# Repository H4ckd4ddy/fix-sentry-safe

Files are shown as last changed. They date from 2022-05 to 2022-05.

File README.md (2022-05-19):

# How to fix a safe

A vulnerability allow to open electronic safes from Sentry Safe and Master Lock without any pin code.

This repository contain alternative PCB and firmware to patch this issue.

For more detail about the vulnerability, [check this repo](https://github.com/H4ckd4ddy/bypass-sentry-safe)

### PCB

| Version | Design | Description |
| :-----: | :---: | :--- |
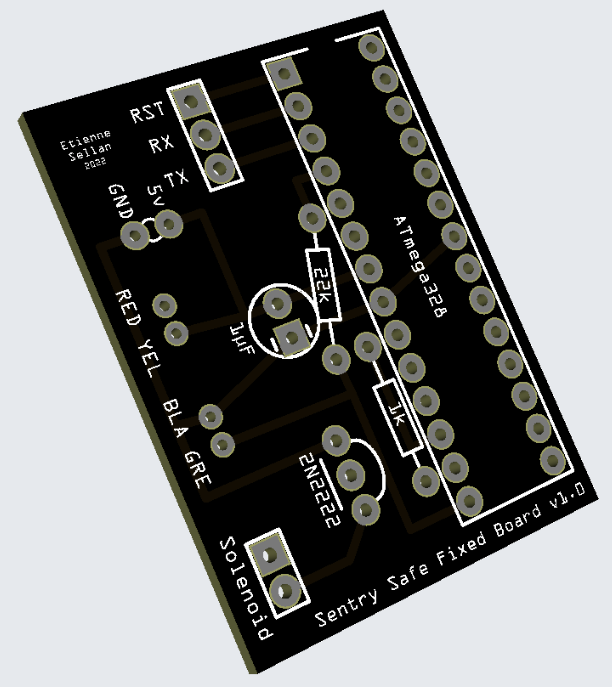
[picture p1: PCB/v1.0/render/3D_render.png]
| v1.0 |  | Only ATmega328, basic offline features |
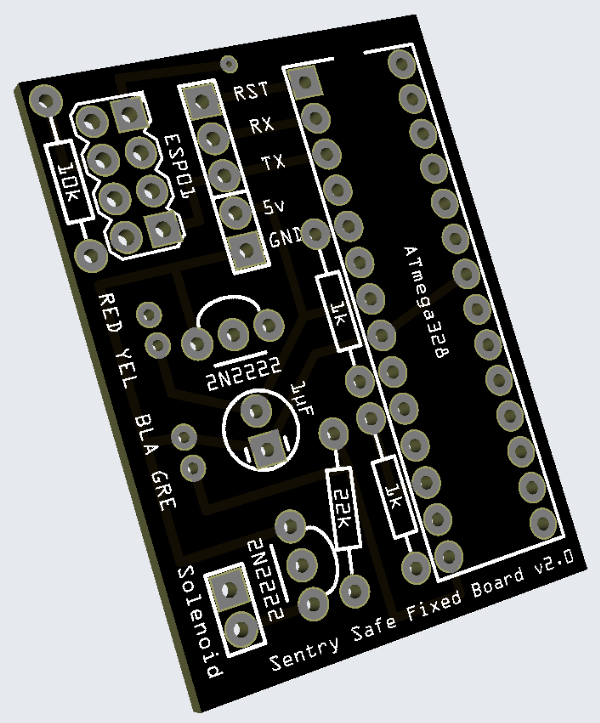
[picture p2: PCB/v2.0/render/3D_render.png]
| v2.0 |  | With esp8266, OTP or remote control support |

### Firmware

⚠️ This is only a PoC for the moment ⚠️

4 modes :

- Static code
- OTP
- Static code OR OTP
- Static code AND OTP

### Setup

- Get PCB
- Solder components
- Flash firmware
- Plug it inside safe door, in place of original board
- Enjoy

### Pictures

Module ready

Board installed

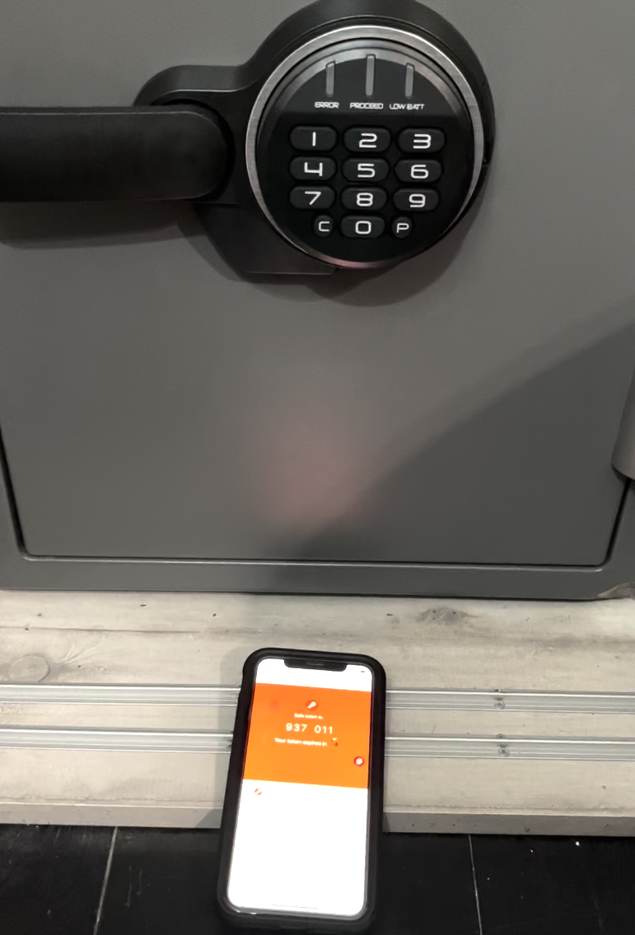
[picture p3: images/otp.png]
OTP setup


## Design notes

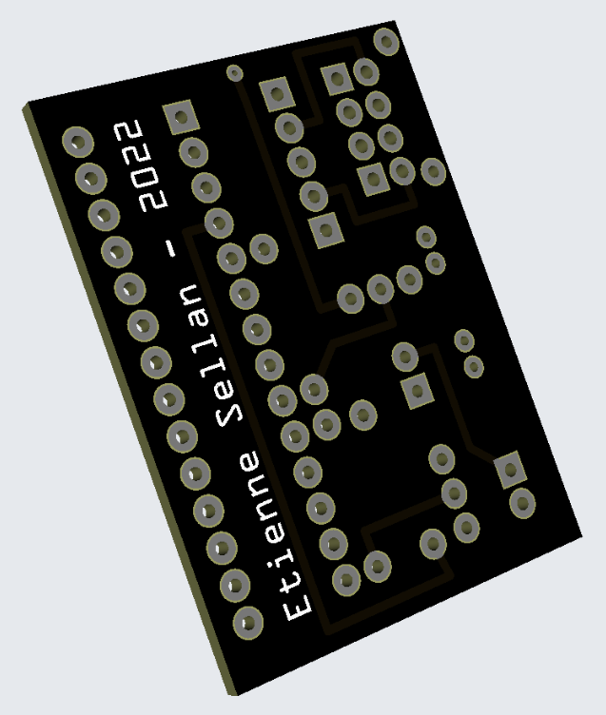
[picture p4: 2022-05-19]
PCB/v2.0/render/3D_render_back.png

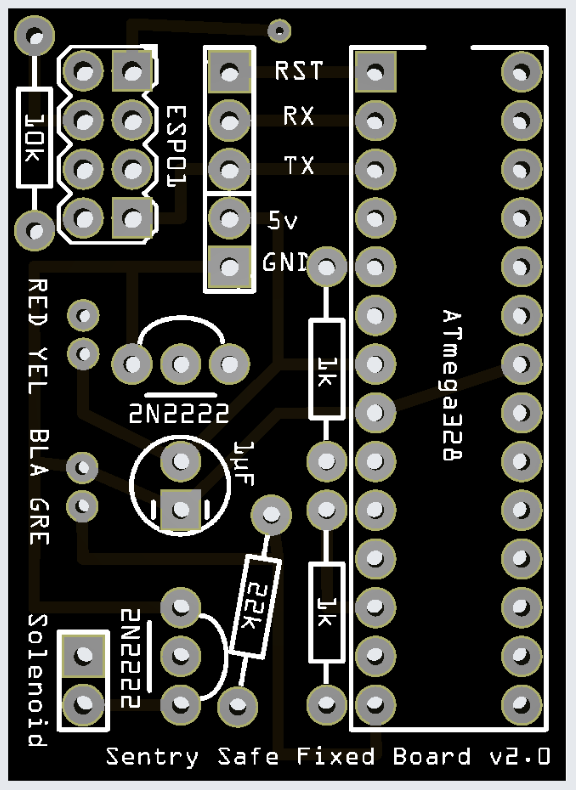
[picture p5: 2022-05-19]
PCB/v2.0/render/render.png

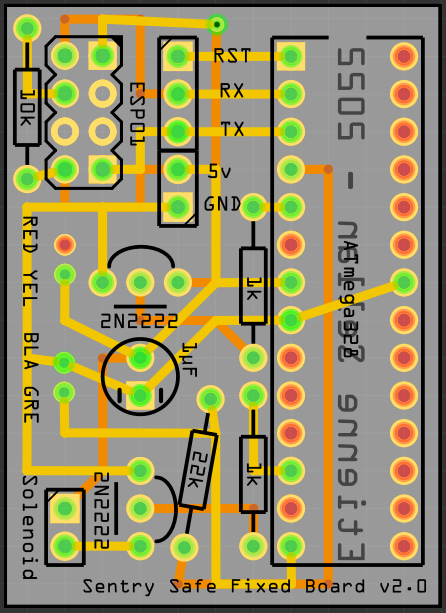
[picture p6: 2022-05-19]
PCB/v2.0/render/fritzing.png

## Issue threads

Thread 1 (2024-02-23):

PCB

sspencer10, 2024-02-23:
The board you are holding in your hand in the README says version 2.1. What's changed on that board from version 2.0 found in the PCB directory?

H4ckd4ddy, 2024-02-23:
Hi,
Well done, I wondered if anyone would notice.
On 2.0, main microcontroller is maintained in deep sleep, and wake up when a signal is received from keypad (green wire)
On 2.1, I tried to add a PNP transistor between green wire and microcontroller wake up pin, to reduce even more sleep power consumption.
But it's useless and do not work properly. As you can see on the picture, at the bottom of PCB, the PNP transistor is not even assembled.
Best regards

sspencer10, 2024-02-24:
Ok, thanks for the explanation. You can mark as closed. Nice work on this project. Very interesting!

Closed 2024-02-24.

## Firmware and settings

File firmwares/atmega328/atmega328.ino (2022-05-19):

#include <SingleWireSerial.h>
SingleWireSerial front_keypad(false);
#include "LowPower.h"
#include <EEPROM.h>

/* Modes
 *  
 *  1 = static code
 *  2 = OTP
 *  3 = OTP or static code
 *  4 = static code and OTP
 */
const byte mode = 1;

// I/O defs
const int wakeUpPin = 2;
const int lock_pin = 6;
const int esp_pin = 3;

const int signal_offset = 2;//bytes
int code_length = 5;
byte request[9];
int request_length = 0;
bool change_code = false;
bool wait_otp = false;

// Anti bruteforce settings
const int max_wrong_code = 3;
const int reset_locking_timer = 60;//sec
long last_lock = 0;

// EEPROM address settings
const int eeprom_code_start_addr = 0;
const int wrong_code_count_addr = 100;

// Timers settings
const int open_timer = 3;//sec
const int sleep_timer = 3;//sec
const int change_timer = 10;//sec
const int wait_otp_timer = 15;//sec
long last_wake;

void setup() {
  Serial.begin(4800);
  front_keypad.begin(4800);
  
  pinMode(wakeUpPin, INPUT_PULLUP);
  pinMode(lock_pin, OUTPUT);
  digitalWrite(lock_pin, LOW);
  pinMode(esp_pin, OUTPUT);
  digitalWrite(esp_pin, LOW);
  
  enter_sleep_mode();
}

long seconds(){
  return (millis()/1000);
}

void clear_request_data(){
  request_length = 0;
  memset(request, 0, sizeof(request));
}

void enter_sleep_mode(){
  clear_request_data();
  change_code = false;
  wait_otp = false;

  attachInterrupt(0, wakeUp, LOW);
  delay(1000);
  LowPower.powerDown(SLEEP_FOREVER, ADC_OFF, BOD_OFF);
  detachInterrupt(0);
  last_wake = seconds();
}


void wakeUp(){}

void loop() {

  // Receive keypad messages
  if (front_keypad.available() > 0) {
    byte input = front_keypad.read();
   
    request[request_length] = input;
    request_length++;
    
    if(request_length >= sizeof(request)){
      switch(request[2]){
        case 113: try_unlock();break;
        case 116: ask_change();break;
        case 117: set_code();break;
        case 120: send_reply(0x58, 0x1, 0x0, 0x1);break;
        default: break;
      }
      clear_request_data();
    }
  }

  if(!is_locked()){// Do not sleep if locked, cause timer stop in sleep mode
    if((((seconds() - last_wake) > sleep_timer) && !change_code) || (((seconds() - last_wake) > change_timer) && change_code)){
      enter_sleep_mode();
    }
  }
}

bool check_code(){

  if(is_locked()){
    return false;
  }
  
  bool match = true;
  for(int i = 0;i < code_length;i++){
    if(EEPROM.read(eeprom_code_start_addr+i) != request[i+3]){
      match = false;
    }
  }

  if(!match){
    add_wrong_code();
  }
  
  return match;
}

bool check_otp(){

  digitalWrite(esp_pin, HIGH);
  delay(1000);
  Serial.readStringUntil('#');
  delay(100);
  while(Serial.available() == 0){
    delay(1);  
  }
  String otp = Serial.readStringUntil('\r');
  digitalWrite(esp_pin, LOW);
  
  bool match = true;
  for(int i = 0;i < code_length;i++){
    if(byte(otp[i]-48) != request[i+3]){
      match = false;
    }
  }
  return match;
}

void try_unlock(){

  if(wait_otp || mode == 2){
    send_reply(0x51, 0x1, 0x0, 0x1);
    if(check_otp()){
      open();
    }
    wait_otp = false;
    enter_sleep_mode();
  }else if(check_code()){
    if(mode == 4){
      send_reply(0x51, 0x1, 0x0, 0x1);
      wait_otp = true;
      last_wake += wait_otp_timer;
    }else{
      send_reply(0x51, 0x1, 0x0, 0x1);
      open();
    }
  }else if(mode == 3){
    send_reply(0x51, 0x1, 0x0, 0x1);
    if(check_otp()){
      open();
    }
  }
}

void ask_change(){
  if(check_code()){
    change_code = true;
    send_reply(0x54, 0x1, 0x0, 0x2);
  }
}

void set_code(){
  if(change_code){
    for(int i = 0;i < code_length;i++){
      EEPROM.write(eeprom_code_start_addr+i, request[i+3]);
    }
    change_code = false;
    send_reply(0x55, 0x1, 0x0, 0x2);
  }
}

bool is_locked(){
  bool locked = (EEPROM.read(wrong_code_count_addr) >= max_wrong_code);
  if(locked){
    if(!last_lock){
      last_lock = seconds();
    }
    if((seconds() - last_lock) >= reset_locking_timer){
      last_lock = 0;
      reset_wrong_code_count();
      return false;
    }
  }
  
  return locked;
}

void open(){
  digitalWrite(lock_pin, HIGH);
  delay(open_timer*1000);
  digitalWrite(lock_pin, LOW);
}

void add_wrong_code(){
  EEPROM.write(wrong_code_count_addr, EEPROM.read(wrong_code_count_addr)+1);
}

void reset_wrong_code_count(){
  EEPROM.write(wrong_code_count_addr, 0);
}

void send_reply(byte command, byte data_a, byte data_b, byte data_c){
  byte checksum = (command + data_a + data_b + data_c);
  front_keypad.write(0x0);
  front_keypad.write(command);
  front_keypad.write(data_a);
  front_keypad.write(data_b);
  front_keypad.write(data_c);
  front_keypad.write(checksum);
}

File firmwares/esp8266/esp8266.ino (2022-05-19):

#include <ESP8266WiFi.h>
#include <WiFiManager.h>
#include <uri/UriBraces.h>
#include <WiFiUdp.h>
#include <NTPClient.h>
#include <TOTP.h>

WiFiClient client;

// Your hmacKey (10 bytes)
uint8_t hmacKey[] = {0x00, 0x00, 0x00, 0x00, 0x00, 0x00, 0x00, 0x00, 0x00, 0x00};

WiFiUDP ntpUDP;
NTPClient timeClient(ntpUDP);
TOTP totp = TOTP(hmacKey, 10);

void setup() {

  Serial.begin(4800);
  
  WiFiManager wifiManager;
  wifiManager.setDebugOutput(false);
  wifiManager.autoConnect("Safe");

  // start the NTP client
  timeClient.begin();
  timeClient.update();
  String code = String(totp.getCode(timeClient.getEpochTime()));
  
  Serial.print('#');
  Serial.println(code);
}

void loop(){}
